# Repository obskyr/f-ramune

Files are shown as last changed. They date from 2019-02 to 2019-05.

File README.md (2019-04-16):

# F-Ramune

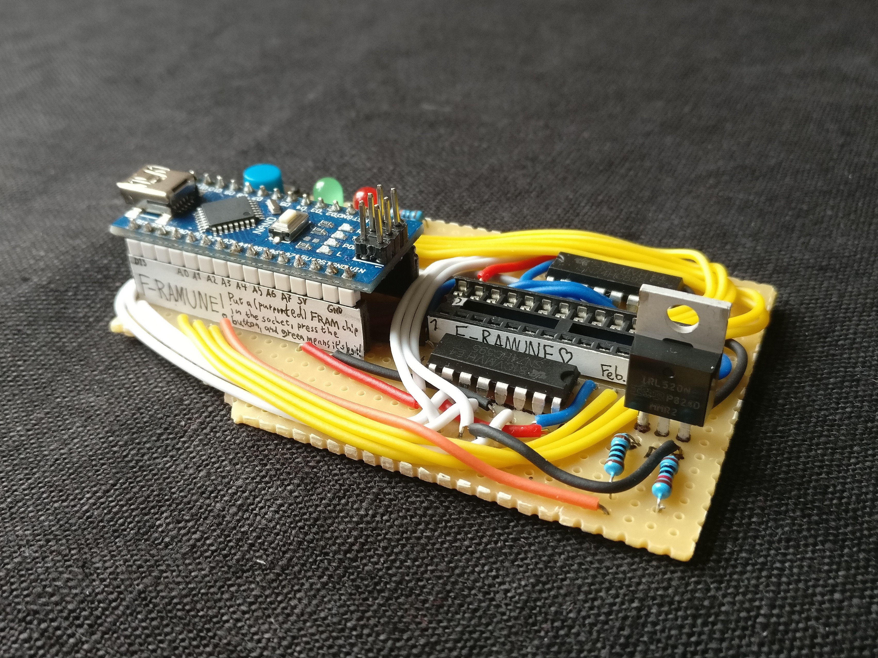
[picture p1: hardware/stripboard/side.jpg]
F-Ramune


F-Ramune is a device that lets you test and program 28-pin FRAM chips (e.g. the FM1808 family)! It lets you:

* Test that a chip is genuine FRAM!
* Test that all of the memory cells of an FRAM chip work!
* Identify a memory chip (size, non-volatility, etc.)
* Read from an FRAM chip!
* Write to an FRAM chip!

It features a reprogrammable pushbutton that lets you quickly test chips – out of the box, it's set to check that a chip is 32 KiB of genuine FRAM in full working order – and a serial interface with accompanying software that lets you program your memory chips from your PC.

I made this to test FM1808s of dubious (i.e. cheap Chinese) origin so that the Game Boy cartridge immortalization mod (link to come) would become more feasible and accessible. I expect that to be the main use of F-Ramune, but it's written in an extensible fashion – if you want to test or program FRAM (or SRAM!) in a different form factor or pinout, not much needs to be changed.

## Getting started

Since F-Ramune is a physical device, you'll first need to build that device. Instructions for this can be found in the [hardware directory](hardware) of the repo. At the moment, there's no PCB version, so it's fairly involved – you have to manually route it on stripboard or breadboard – but it's more than doable.

Once you've built the device, you need to upload the firmware to it. For user-friendliness, F-Ramune's firmware is Arduino-based! Open `software.ino` (in the [`software` directory](software)) in the [Arduino IDE](https://www.arduino.cc/en/main/software), set the board to "Arduino Nano", and click the "upload" button. Bam! Your F-Ramune is now ready to go!

## How to test a chip

Put the chip you want to test in the socket. Press the button to test the chip. Out of the box, upon pressing the button, the LEDs will possibly flash back and forth a bit while testing, and finally indicate:

* **Red** if the chip is 32 KiB of genuine FRAM.
* **Red and green** if the chip is genuine, but faulty memory cells were found.
* **Green** if the chip is 32 KiB of genuine FRAM.

The function of the button can be reprogrammed in [`software.ino`](software/software.ino), if you'd like to check for other traits.

## How to program or analyze a chip

Plug the F-Ramune Arduino into your PC, and put the chip you want to test in the socket. Using the command-line program `framune.py` (found in the `software` directory; requires [Python 3](https://www.python.org/downloads/)) , you can read from, write to, and analyze the properties of the chip. Run `framune.py --help` for details.

## Cool!

F-Ramune is just one part of a larger project, and it's fairly niche, so my instructions here are more terse than they usually are. But fear not! If you have any questions, there are any issues, or you just want to talk, you can contact me in the following ways:

* [@obskyr](https://twitter.com/obskyr) on Twitter, or
* [E-mail](mailto:powpowd@gmail.com) me!

For a quick response, writing to me on Twitter is your best bet. If you built F-Ramune, especially, I would *love* to hear about it!

Enjoy! ☆

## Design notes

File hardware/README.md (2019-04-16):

# The F-Ramune hardware

As of yet, there's no PCB version of F-Ramune, but here are some instructions for building it on stripboard or breadboard!

The bill of materials is as following:

| Part | Description | Number required |
| --- | --- | --- |
| Arduino Nano | | 1 |
| ZIF Socket with DIP-28 footprint | To fit SMD parts a [SOIC-28 ZIF socket](https://www.adafruit.com/product/1281). To also be compatible with DIP chips, a DIP-28 ZIF socket can be used as the bottom layer in a… socket cake. | 1
| 74HC595 | 8-bit SIPO shift register | 2 |
| IRL520N | N-channel MOSFET | 1 |
| Green LED | | 1 |
| Red LED | | 1 |
| Pushbutton | | 1 |
| 10 kΩ resistor | | 1 |
| 100 Ω resistor | | 1 |
| 330 Ω resistor | | 2 |

## Tips for all versions

The schematic specifies the transistor to be an IRL520N, but **any N-channel MOSFET with an I<sub>D</sub>** (drain current) **of 200 mA or higher, a V<sub>GS</sub>** (gate threshold) **of 4.5 V or lower and an R<sub>DS(ON)</sub>** (on-resistance) **of 1 Ω or lower works**. The V<sub>GS</sub> requirement is for ~5 V logic signals to work. The R<sub>DS(ON)</sub> of 1 Ω is calculated based on an assumed max supply current for the memory chip of 200 mA and a max allowable voltage drop of 0.2 V (0.2 A / 0.2 V = 1 Ω). Using a more realistic max supply current of 140 mA and/or a more forgiving voltage drop limit, you can arrive at a higher max R<sub>DS(ON)</sub>, and it'll probably still work fine – albeit with less leeway. If you've got MOSFETs lying around, check out their datasheets and see if they're reasonably close to the requirements!

<!-- For the eventual PCB version:
## PCB

### Tips for the PCB version

* The schematic specifies an 18.432 MHz crystal, but if you've got a 16 MHz crystal lying around, you can use that – it'll just make the serial communication less reliable (0% timing error for 18.432 MHz vs. ~3.5% error for 16). This might still work fine, but it's possible it'll cause trouble with some serial adapters. 
-->

## Stripboard

There's no layout diagram for building F-Ramune on stripboard (since apparently there's no good digital stripboard design program!?), but it's a very reliable and permanent way to build it, so why not give it a shot? Using [the schematic](breadboard-schematic.png), you can put together something most respectable. Here's my finished stripboard:

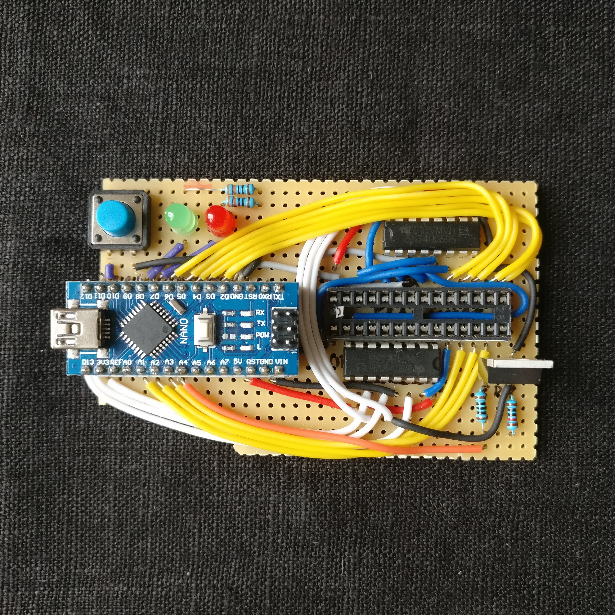
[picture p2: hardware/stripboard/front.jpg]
Stripboard front
  
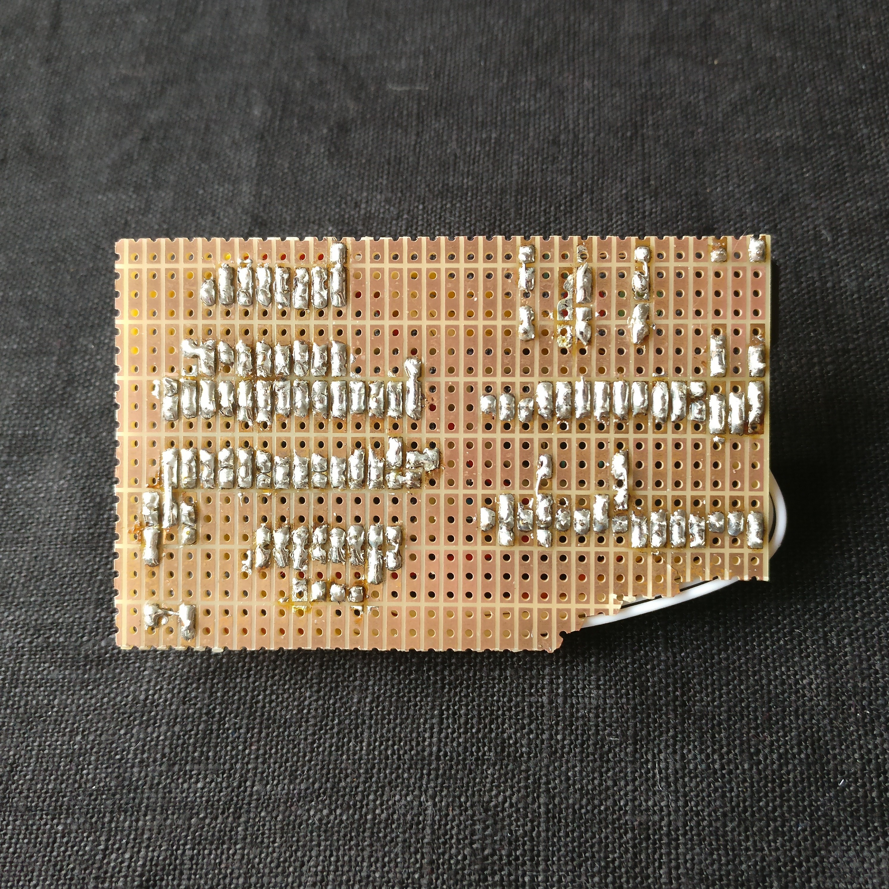
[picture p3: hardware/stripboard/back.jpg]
Stripboard back
  

Don't make the mistake I did and leave too little space for the socket – preferably, solder in whatever socket you're using *before* any wires. Measure twice, cut once, y'know?

## Breadboard

I wouldn't recommend breadboarding F-Ramune – breadboards are unreliable, and the device uses high-speed signals and has to be quite picky with voltages. If you would like to try, though, the breadboard schematic and layout can be found in `breadboard.fzz`, which is a [Fritzing](http://fritzing.org/) file. Either install Fritzing and open that file, or take a gander at the image versions of [the schematic](breadboard-schematic.png) and [the layout diagram](breadboard.png). The layout is somewhat optimistically routed, so some spur-of-the-moment re-routings may need to be done as space gets tight. Here's the finished product:

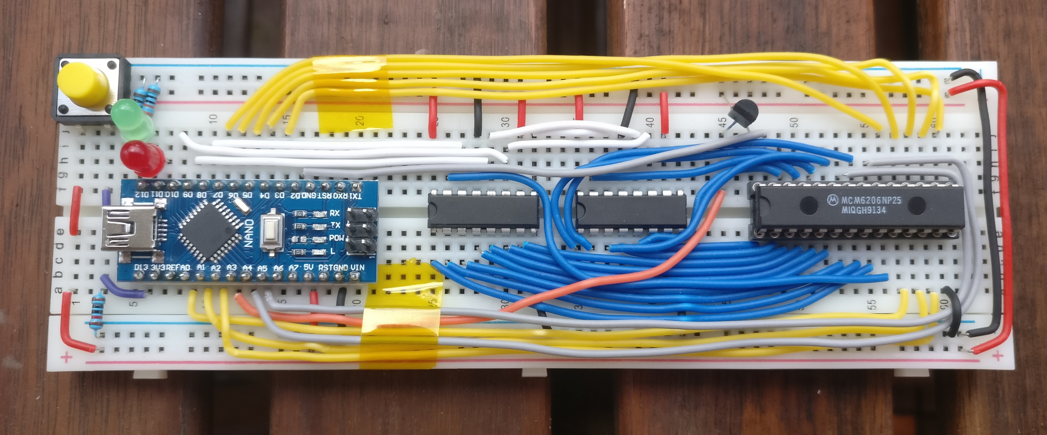
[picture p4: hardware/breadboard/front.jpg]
Routed breadboard


### Tips for breadboarding F-Ramune

* Use a high-quality breadboard! Although FRAM chips consume next to no current, SRAM chips can consume up to 140 mA. Channeling that much via a breadboard with poor connections and bizarrely resistive power rails is a fool's errand – I learned this the hard way.
* If you're using a breadboard of lesser quality, keep the following in mind:
    * When you insert a wire or a pin, make sure it feels like it's being gripped (and before you insert an IC, check those holes with a wire first). If it doesn't, that hole may be intermittent or flat-out broken. You can remedy this by using a different hole on the same row, replacing the strip on that particular row, or [jamming a resistor leg into it](https://twitter.com/obskyr/status/1096047043683012609).
    * You may need to run wires directly to the memory chip's V+ and ground pins from the holes right by the Arduino, since going via the power rails might prove too high-resistance. Adding more bridge wires (like the ones on the far right in the breadboard diagram) may also help, albeit not as much.
* The pins on a TO-220 package such as the MOSFET here are highly destructive to breadboard holes. Use a gripping implement to turn the thin part of the pins 45–90° before inserting it, so the pins don't get gripped lengthwise and bend the breadboard's connectors out of shape.

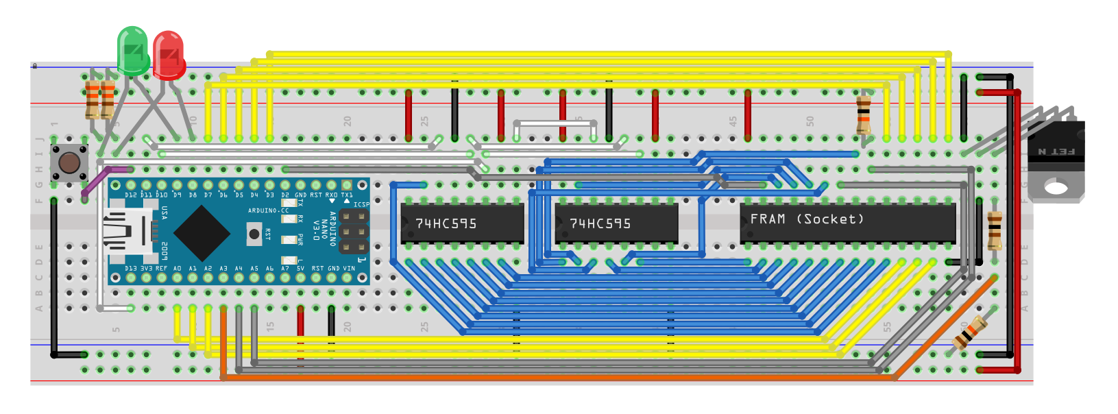
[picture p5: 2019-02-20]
hardware/breadboard/breadboard.png

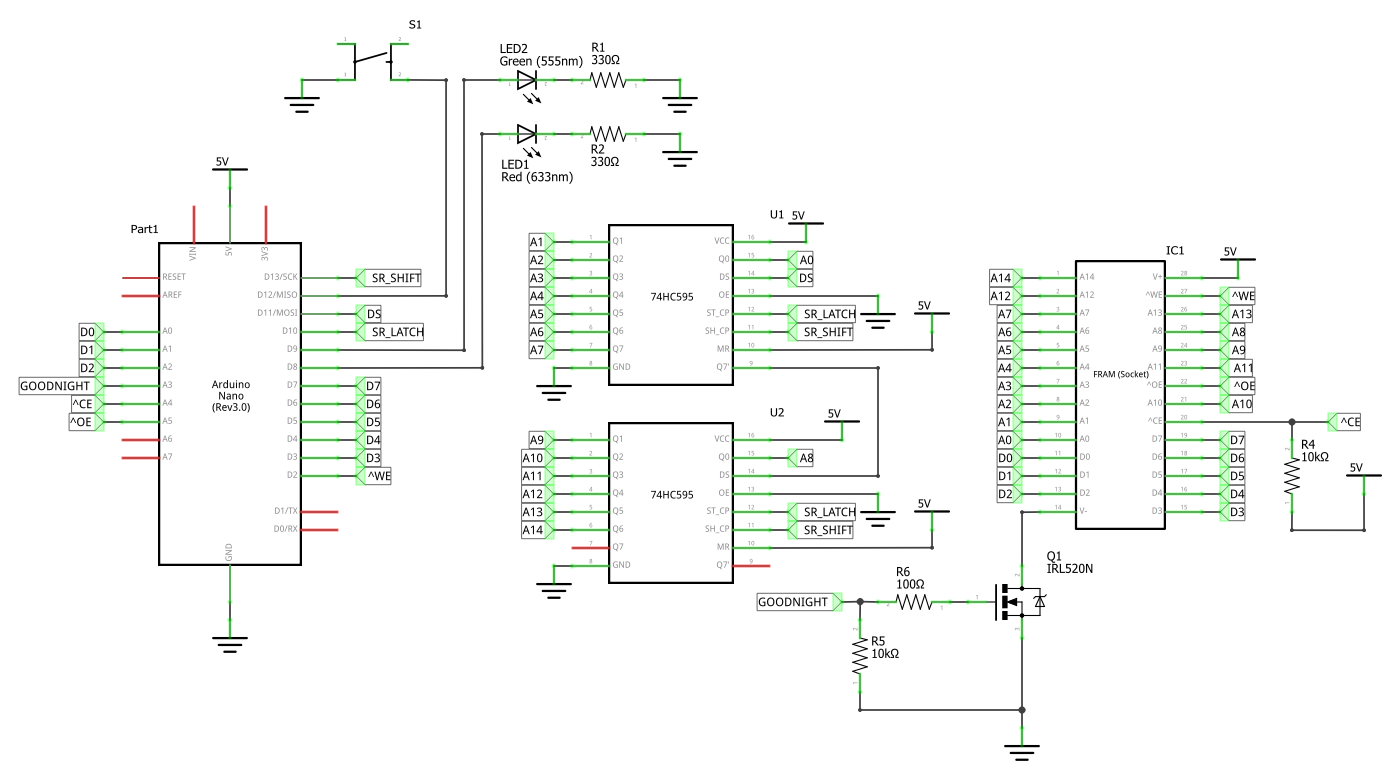
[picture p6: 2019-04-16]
hardware/breadboard/breadboard_schematic.png

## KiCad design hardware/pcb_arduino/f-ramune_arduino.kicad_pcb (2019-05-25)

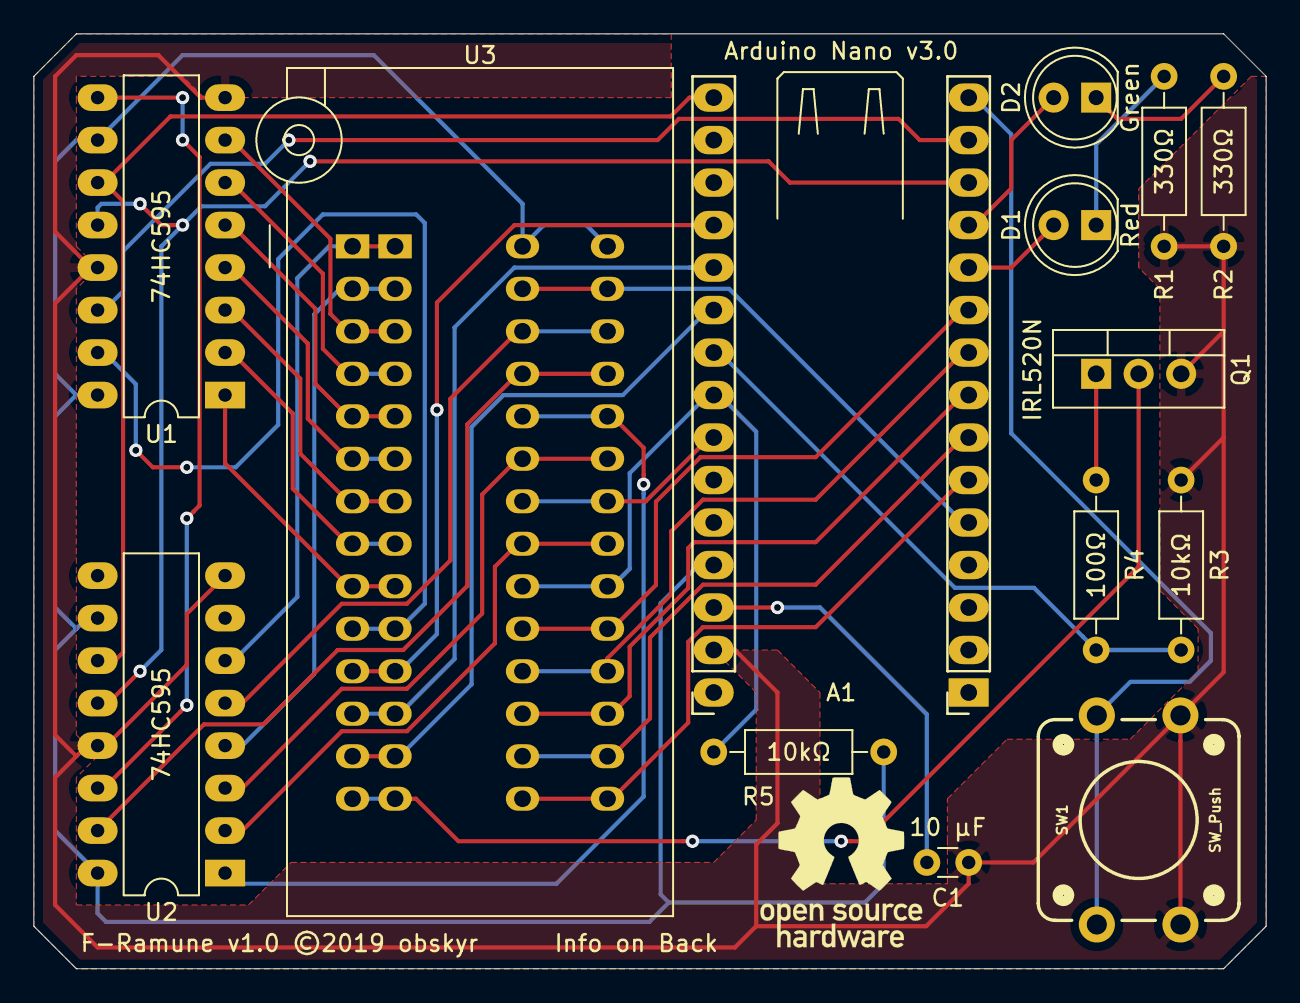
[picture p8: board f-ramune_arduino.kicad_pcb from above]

Board: 2 copper layers, 73.7 x 55.9 mm, 14 parts (0 on the bottom side), 41 nets.

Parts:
A1: Arduino Nano v3.0; Socket_Strip_Arduino_Nano
C1: 10 µF; C_Disc_D3.0mm_W1.6mm_P2.50mm
D1: Red; LED_D5.0mm
D2: Green; LED_D5.0mm
Q1: IRL520N; TO-220-3_Vertical
R1, R2: 330Ω; R_Axial_DIN0207_L6.3mm_D2.5mm_P10.16mm_Horizontal
R3, R5: 10kΩ; R_Axial_DIN0207_L6.3mm_D2.5mm_P10.16mm_Horizontal
R4: 100Ω; R_Axial_DIN0207_L6.3mm_D2.5mm_P10.16mm_Horizontal
SW1: SW_Push; TACTILE_SWITCH_PTH_12MM
U1, U2: 74HC595; DIP-16_W7.62mm_LongPads
U3: Memory (Socket); ZIF_Socket_DIP-28_With_Alternatives

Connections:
+5V: A1.27, R5.1, U1.10, U1.16, U2.10, U2.16, U3.28
A0: U1.15, U3.10
A1: U1.1, U3.9
A2: U1.2, U3.8
A3: U1.3, U3.7
A4: U1.4, U3.6
A5: U1.5, U3.5
A6: U1.6, U3.4
A7: U1.7, U3.3
A8: U2.15, U3.25
A9: U2.1, U3.24
A10: U2.2, U3.21
A11: U2.3, U3.23
A12: U2.4, U3.2
A13: U2.5, U3.26
A14: U2.6, U3.1
D0: A1.19, U3.11
D1: A1.20, U3.12
D2: A1.21, U3.13
D3: A1.6, U3.15
D4: A1.7, U3.16
D5: A1.8, U3.17
D6: A1.9, U3.18
D7: A1.10, U3.19
GND: A1.29, C1.1, Q1.3, R1.2, R2.2, R3.1, SW1.1, U1.8, U1.13, U2.8, U2.13
Goodnight: A1.22, R3.2, R4.2
unnamed: A1.11, D1.2
unnamed: A1.12, D2.2
unnamed: A1.15, SW1.2
unnamed: A1.28, C1.2
unnamed: D1.1, R1.1
unnamed: D2.1, R2.1
unnamed: Q1.1, R4.1
unnamed: Q1.2, U3.14
unnamed: U1.9, U2.14
SR_Data: A1.14, U1.14
SR_Latch: A1.13, U1.12, U2.12
SR_Shift: A1.16, U1.11, U2.11
~CE: A1.23, R5.2, U3.20
~OE: A1.24, U3.22
~WE: A1.5, U3.27

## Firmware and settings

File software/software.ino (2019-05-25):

#include <Bounce2.h>
#include "channelio.hpp"
#include "memorychip.hpp"
#include "serialinterface.hpp"

// If you want to use an MCU or pinout other than the ones found in the
// hardware directory, change these settings here to your liking. 
#if !defined(PCB_LAYOUT) && (defined(BREADBOARD_LAYOUT) || defined(ARDUINO_AVR_NANO))

// Memory chip control pins
#define PIN_MEMORY_POWER A3
#define PIN_MEMORY_POWER_ON_STATE HIGH
#define PIN_MEMORY_CE    A4
#define PIN_MEMORY_OE    A5
#define PIN_MEMORY_WE    2

// Memory chip address channel
// Latch pin: 10 (SS - doesn't need to be SS, but might as well be)
// When SPI is active, don't forget: MISO's direction is overridden
// to be an input (but the pull-up is still available), and SS has to
// stay configured as an output to stay master!
// Within those config constraints, though, they can be used for unrelated IO.
Output_SpiShiftRegister<uint16_t> ADDRESS_CHANNEL(20000000, SPI_MODE0, 10);

// Memory chip data channel
// Note that INPUT_PULLUP here is important - otherwise, reading when there's
// no chip connected will read back what was just written (ghooost values).
// 5 bits starting at bit #3, via port D
InputOutput_Port DATA_CHANNEL_PORT_1(INPUT_PULLUP, &PIND, &PORTD, &DDRD, 3, 3, 5);
// 3 bits starting at bit #0, via port C
InputOutput_Port DATA_CHANNEL_PORT_2(INPUT_PULLUP, &PINC, &PORTC, &DDRC, 0, 0, 3);
InputOutput_Port* DATA_CHANNEL_PORTS[] = {
    &DATA_CHANNEL_PORT_1,
    &DATA_CHANNEL_PORT_2
};
InputOutputChannelSet<uint8_t, InputOutput_Port> DATA_CHANNEL(
    sizeof(DATA_CHANNEL_PORTS) / sizeof(*DATA_CHANNEL_PORTS),
    DATA_CHANNEL_PORTS
);

// Buttons 'n' lights
#define PIN_TEST_BUTTON 12
#define PIN_HAPPY_LED    9
#define PIN_FROWNY_LED   8

#else

// I decree that the IO settings for the circuit board version shall go here.

#endif

MemoryChip MEMORY_CHIP(&ADDRESS_CHANNEL, &DATA_CHANNEL,
                       PIN_MEMORY_CE, PIN_MEMORY_OE, PIN_MEMORY_WE,
                       PIN_MEMORY_POWER, PIN_MEMORY_POWER_ON_STATE);
SerialInterface SERIAL_INTERFACE(&Serial, &MEMORY_CHIP);

Bounce TEST_BUTTON = Bounce();

void testChip()
{
    MemoryChipKnownProperties prevKnownProperties;
    MemoryChipProperties prevProperties;
    MEMORY_CHIP.getProperties(&prevKnownProperties, &prevProperties);
    MEMORY_CHIP.analyze();
    MemoryChipKnownProperties knownProperties;
    MemoryChipProperties properties;
    MEMORY_CHIP.getProperties(&knownProperties, &properties);

    if (!(knownProperties.isOperational && properties.isOperational)) {
        // No chip connected: li'l "wat?" animation.
        int i = 0;
        int timesToBlink = 3;
        while (i < timesToBlink) {
            digitalWrite(PIN_HAPPY_LED, HIGH);
            digitalWrite(PIN_FROWNY_LED, HIGH);
            delay(333);
            digitalWrite(PIN_HAPPY_LED, LOW);
            digitalWrite(PIN_FROWNY_LED, LOW);
            i++;
            if (i < timesToBlink) {delay(333);}
        }
    } else if (!(
        // To change the properties the test button tests, change these here criteria!
        // These criteria test that the chip is fast 32 KiB non-volatile memory.
        // That is, FRAM. (Or something equivalent, but it's gonna be FRAM.)
        (knownProperties.size && properties.size == 0x8000) &&
        (knownProperties.isNonVolatile && properties.isNonVolatile) &&
        (knownProperties.isSlow && !properties.isSlow)
    )) {
        // Incorrect properties: red light.
        digitalWrite(PIN_FROWNY_LED, HIGH);
    } else {
        // And for posterity, we test that all memory cells work, too.
        // Since testing *all* addresses takes some time, this requires
        // a little "working..." animation.
        uint8_t blinkState = HIGH;
        digitalWrite(PIN_HAPPY_LED, HIGH);
        unsigned long int prevBlinkMillis = millis();
        bool allAddressesWork = true;
        for (uint32_t windowStart = 0; windowStart < properties.size; windowStart += 512) {
            uint32_t windowEnd = windowStart + 512;
            windowEnd = windowEnd <= properties.size ? windowEnd : properties.size;
            if (!MEMORY_CHIP.addressesWorkBetween(windowStart, windowEnd)) {
                allAddressesWork = false;
                break;
            }

            unsigned long int curMillis = millis();
            if (curMillis - prevBlinkMillis >= 333) {
                blinkState = !blinkState;
                digitalWrite(PIN_HAPPY_LED, blinkState);
                digitalWrite(PIN_FROWNY_LED, !blinkState);
                prevBlinkMillis = curMillis;
            }
        }

        digitalWrite(PIN_HAPPY_LED, LOW);
        digitalWrite(PIN_FROWNY_LED, LOW);
        delay(333);
        if (allAddressesWork) {
            // Correct properties and all cells working: green light.
            digitalWrite(PIN_HAPPY_LED, HIGH);
        } else {
            // Correct properties but broken memory cells: green and red light.
            digitalWrite(PIN_HAPPY_LED, HIGH);
            digitalWrite(PIN_FROWNY_LED, HIGH);
        }

        // If you don't want to test the entire address space,
        // comment out the rest of this block and uncomment this line:
        // digitalWrite(PIN_HAPPY_LED, HIGH);
    }

    MEMORY_CHIP.setProperties(&prevKnownProperties, &prevProperties);
}

void setup()
{
    Serial.begin(115200);
    MEMORY_CHIP.initPins();
    TEST_BUTTON.attach(PIN_TEST_BUTTON, INPUT_PULLUP);
    TEST_BUTTON.interval(25);
    pinMode(PIN_HAPPY_LED, OUTPUT);
    pinMode(PIN_FROWNY_LED, OUTPUT);
}

void loop()
{
    TEST_BUTTON.update();
    if (!SERIAL_INTERFACE.update()) {
        if (TEST_BUTTON.fell()) {
            digitalWrite(PIN_HAPPY_LED, LOW);
            digitalWrite(PIN_FROWNY_LED, LOW);
        } else if (TEST_BUTTON.rose()) {
            MEMORY_CHIP.powerOn();
            testChip();
            MEMORY_CHIP.powerOff();
        }
    }
}

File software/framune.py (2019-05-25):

#!/usr/bin/env python3

import argparse
import json
import os
import struct
import sys
import serial
from binascii import crc32
from collections import OrderedDict
from contextlib import contextmanager

BAUD_RATE = 115200
MIN_TIMEOUT = 1

PROTOCOL_VERSION = 0
ENDIANNESS = '>'

def serial_without_dtr(port, *args, **kwargs):
    """Construct a Serial object with DTR immediately disabled.
    On systems where pySerial supports this, this will prevent an Arduino from
    resetting when a serial connection is opened. On other systems, a hardware
    workaround (e.g. a 10 µF capacitor between RST and ground) is needed.
    """
    ser = serial.Serial(None, *args, **kwargs)
    ser.port = port
    ser.dtr = 0
    if port is not None: # To match what pySerial does.
        ser.open()
    return ser

def appropriate_timeout(length):
    """Return a reasonable timeout value for transferring `length`
    bytes at F-Ramune's baud rate."""
    return max(MIN_TIMEOUT, 1.5 * (length / (BAUD_RATE // 8)))

@contextmanager
def temp_timeout(ser, timeout):
    original_timeout = ser.timeout
    ser.timeout = timeout
    yield
    ser.timeout = original_timeout

class Framune(object):
    def __init__(self, serial_port):
        if hasattr(serial_port, 'port'):
            self.serial_port = serial_port.port
            self._serial = serial_port
        else:
            self.serial_port = serial_port
            self._serial = serial_without_dtr(serial_port, BAUD_RATE,
                                              timeout=MIN_TIMEOUT,
                                              inter_byte_timeout=MIN_TIMEOUT)
        self._chip = MemoryChip(None, None, None, None, framune=self)
    
    def __enter__(self):
        return self

    def __exit__(self, *args):
        self.close()

    def close(self):
        self._serial.close()
    
    @property
    def chip(self):
        return self._chip
    
    @chip.setter
    def chip(self, chip):
        self._set_and_analyze_chip(chip)
    
    def _read(self, length=1):
        try:
            data = self._serial.read(length)
            if len(data) < length:
                raise TimeoutError
        except (serial.SerialTimeoutException, TimeoutError):
            raise TimeoutError("F-Ramune did not respond in time.")
        else:
            return data
    
    def _write(self, data):
        self._serial.write(data)

    def _read_uint(self, fmt, length):
        return struct.unpack(fmt, self._read(length))[0]
    
    def _write_uint(self, fmt, n):
        self._write(struct.pack(fmt, n))

    def _read_byte(self):
        return self._read_uint(ENDIANNESS + 'B', 1)
    
    def _write_byte(self, n):
        self._write_uint(ENDIANNESS + 'B', n)
    
    def _read_uint16(self):
        return self._read_uint(ENDIANNESS + 'H', 2)

    def _write_uint16(self, n):
        self._write_uint(ENDIANNESS + 'H', n)

    def _read_uint32(self):
        return self._read_uint(ENDIANNESS + 'I', 4)

    def _write_uint32(self, n):
        self._write_uint(ENDIANNESS + 'I', n)

    def _command(self, command):
        self._write_byte(command)
        if self._read_byte() == command:
            self._write_byte(0x00)
        else:
            self._write_byte(0x01)
            raise ConnectionError("Command didn't reach F-Ramune intact.")
    
    def _set_and_analyze_chip(self, chip):
        self._command(0x01)
        self._write(chip.known_status_to_bytes())
        self._write(chip.to_bytes())
        self._chip = MemoryChip.from_bytes(
            self._read(MEMORY_CHIP_KNOWN_DATA_STRUCTURE_SIZE),
            self._read(MEMORY_CHIP_DATA_STRUCTURE_SIZE),
            framune=self
        )

    def get_version(self):
        """Return the protocol version of the F-Ramune."""
        self._command(0x00)
        return self._read_uint16()
    
    def version_matches(self):
        """Return True if the F-Ramune has the same protocol version
        as the script does; False if not.
        """
        return self.get_version() == PROTOCOL_VERSION
    
    def analyze(self):
        self._set_and_analyze_chip(MemoryChip(None, None, None, None))

    def read(self, address, length):
        """Return up to `length` bytes read starting at `address` from
        the memory chip currently connected to the F-Ramune.
        """
        self._command(0x02)
        self._write_uint32(address)
        self._write_uint32(length)
        length = self._read_uint32()

        with temp_timeout(self._serial, appropriate_timeout(length)):
            data = self._read(length)
        
        received_crc = self._read_uint32()
        computed_crc = crc32(data)
        if received_crc != computed_crc:
            raise ConnectionError("The computed checksum didn't match the one "
                                  "received from the F-Ramune.")
        
        return data
    
    def write(self, address, data):
        """Write the bytes `data` to the memory chip currently connected to
        the F-Ramune, starting at `address`."""
        length = len(data)
        self._command(0x03)
        # Unused at the moment. Who needs EEPROM support anyway...
        is_slow = self._read_byte()
        self._write_uint32(address)
        self._write_uint32(length)
        length = self._read_uint32()
        data = data[:length]

        with temp_timeout(self._serial, appropriate_timeout(length)):
            self._write(data)
            # Receiving the CRC really only transfers 4 bytes, but the F-Ramune
            # operates on all of the bytes written to compute it, so it takes
            # time, and thus needs a more lenient timeout. appropriate_timeout
            # does that job well enough (it's a bit too lenient here, even).
            received_crc = self._read_uint32()
        error_code = self._read_byte()
        computed_crc = crc32(data)
        if received_crc != computed_crc:
            raise ConnectionError("The computed checksum didn't match the one "
                                  "received from the F-Ramune.")
        if error_code != 0:
            raise ConnectionError("Write failed. "
                                  "Is there really a memory chip connected?")
        return length

def framune_updating_property(internal_name):
    def getter(self):
        return getattr(self, internal_name)
    prop = property(getter)
    def setter(self, value):
        setattr(self, internal_name, value)
        if self._framune is not None:
            self._framune.chip = self
    with_setter = prop.setter(setter)
    return with_setter
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

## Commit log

2019-01-30 Draw schematic.
    Along with adding .gitignore.
    [fram-tester.sch]
2019-01-31 Add Fritzing breadboard diagram.
    [fram-tester_breadboard.fzz]
2019-01-31 Overhaul breadboard to use Arduino Nano.
    Turns out the FM18W08 (as opposed to the regular FM1808) is CMOS logic, which means the lower cutoff for a logical 1 is 3.5V. So... for compatibility, a 3.3V logic MCU needs the ability to switch bet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
    [fram-tester_breadboard.fzz]
2019-01-31 Reroute breadboard a wee bit.
    [fram-tester_breadboard.fzz]
2019-01-31 Nevermind! It was better before.
    [fram-tester_breadboard.fzz]
2019-01-31 Moved FRAM control pins to potentially make way for ICSP.
    [fram-tester_breadboard.fzz]
2019-02-01 Add indicator LEDs and test button to breadboard.
    The ICSP pins be darned for the moment - the breadboard and circuit board versions might as well have different pinouts.
    [fram-tester_breadboard.fzz]
2019-02-02 Reroute breadboard to leave pins 0 and 1 unconnected.
    As it turns out, USB serial goes via pins 0 and 1 on the MCU on the Arduino too, so they can't be connected to other things if serial is used. We're really using ALL the pins! Exciting!
    [fram-tester_breadboard.fzz]
2019-02-09 A whole lot of code!
    A system for arbitrarily implemented IO channels (I may have fallen for overgenericization) and a class for interfacing with memory chips!
    Wow, templates really get messy, don't they? I had to do some seriously impressive somersaults to make separation of API and implementation work both to C++'s and Arduino's constraints at the same ti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
    Oh, and all this is entirely untested. I haven't had the parts to test until just the other day - I've been writing code in the dark. So that's next up, I suppose.
2019-02-09 Fix shifting out too many bits.
    That should be "--", not "++"!
    [channelio.cpp]
2019-02-11 Code galore!
    Lots of fixes (the Arduino IDE lets you turn on -Wall!) and huge optimization. Still isn't fast enough, though.
    Oh, and there's still the minor case of this major bug... https://stackoverflow.com/questions/54632425/is-casting-derived-%e2%86%92-base-wrong-whats-the-alternative
    [channelio.cpp, memorychip.cpp, software.ino]
2019-02-11 Fix ChannelSet compatibility.
    Using templates! Wow!
    [channelio.cpp, software.ino]
2019-02-12 Interface with address shift register via SPI.
    This makes the address setup bizarrely fast, apparently! Good stuff!
    [fram-tester_breadboard.fzz]
2019-02-12 Rename project to f-ramune!
    Enough work has gone into this that it shouldn't have a generic name.
    [breadboard.fzz, f-ramune.sch]
2019-02-13 Add testing code, fix bugs, live life.
    [channelio.cpp, memorychip.cpp, software.ino]
2019-02-14 Initialize control pins properly; change test interface.
    So THAT'S why it seemed like data wasn't persisting across resets. When I was trying to read data back, WE was low, which actually performed a write...
    [memorychip.cpp, software.ino]
2019-02-14 Fix memory potentially being inadvertently written to.
    Memory control pins should start high (inactive), and a pull-up on CE makes sure the memory chip isn't enabled when the control pins are unconfigured.
    Oh, and I flipped a transistor which was the wrong way in the schematic. Whoops!
    [breadboard.fzz]
2019-02-18 Use a low-side MOSFET for switching on/off the memory chip.
    Wow, geez, there are a lot of considerations to be made when cutting power to an IC! This commit implements and explains a whole lot of those.
    The main reason for using a MOSFET over a BJT is that BJTs have fairly high voltage drop, which could potentially be troublesome.
    [breadboard.fzz]
2019-02-18 Move breadboard chips to the left one row.
    Just a liiiittle bit more compact.
    [breadboard.fzz]
2019-02-20 Use internal pull-up resistor for button.
    Turns out the MISO pin, even when overridden to be an input by the SPI peripheral, can use the internal pull-up. That makes one less component!
    [breadboard.fzz]
2019-03-01 Add "set memory chip" serial command.
    Along with a few miscellaneous bug fixes and additions.
    [framune.py, memorychip.cpp, software.ino]
2019-03-01 Make chip analysis work *mwah* just like-a mama used to make.
    Along with integrating chip analysis into the "set chip command" and miscellaneous fixes and such.
    [framune.py, memorychip.cpp, software.ino]
2019-03-01 Finally implement that test button!!!
    You know that test button that really was the entire point of the device? The whole idea? After a bunch of bells and whistles (and a... serial interface!?), it finally does what it set out to do!!!
2019-03-06 KiCAD version of Arduino schematic.
    Along with a li'l bit of restructuring.
    [breadboard.fzz, f-ramune.sch, f-ramune_arduino.kicad_pcb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]
2019-03-09 Add write command; fix bugs.
    That's all the commands!
    [framune.py, memorychip.cpp]
2019-03-28 Have memory chip unpowered during downtime.
    This way, you won't have to switch out the chip while it's powered, which might cause serious trouble.
    [memorychip.cpp, software.ino]
2019-04-16 Pictures and instructions!
    That PCB version has to wait. A guy's gotta have priorities, you know?
2019-04-17 Add a PCB version based on the Arduino stripboard F-Ramune. Should be fabricated on blue soldermask for best results.
    [f-ramune_arduino.kicad_pcb, f-ramune_arduino.sch]
2019-04-17 Add more silkscreen indicators onto the board to make it easier to assemble.
    [f-ramune_arduino.kicad_pcb]
2019-04-17 Built gerber files, ready for prototype production! (No BOM though...)
    [f-ramune_arduino-B_Cu.gbl, f-ramune_arduino-B_Mask.gbs, f-ramune_arduino-B_SilkS.gbo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]
2019-04-18 Last-minute silkscreen changes to indicate LED colors and Arduino orientation. Also, delete the redundant NPTH file as this design only has plated holes.
    It's called last-minute, because the cutoff for changes to my PCB order is 2 hours from now and I just noticed the design issue.
    [f-ramune_arduino-B_Cu.gbl, f-ramune_arduino-B_Mask.gbs, f-ramune_arduino-B_SilkS.gbo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]
2019-04-20 Here's a schematic for a bare-AVR version of F-Ramune, including in-circuit programming functionality (do not use with native USB)
    [f-ramune_avr.sch]
2019-05-24 The pin assignments on this switch footprint are wrong. The switch does not close between the long side of the part's pins - it closes around the short side.
    [f-ramune_arduino.kicad_pcb]
2019-05-24 Also, here's an almost-full SMD AVR version of F-Ramune that will probably never be assembled
    [f-ramune_avr.kicad_pcb, f-ramune_avr.sch]
2019-05-25 Extend delay after powering on chip.
    To support... bizarre FRAM chips that just need a bit to get ready once they've been turned on, for some reason? Very very strange.
    I also took the chance to remove a line of test code I'd forgotten to remove before.
2019-05-25 Fix incorrect copyright date on AVR silkscreen.
    [f-ramune_avr.kicad_pcb]
2019-05-25 Add Gerbers for the AVR/SMD version of F-Ramune.
    [f-ramune_avr-B_Cu.gbl, f-ramune_avr-B_Mask.gbs, f-ramune_avr-B_SilkS.gbo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]
2019-05-25 Update / tidy up the Arduino version and add the instructions on the back
    [f-ramune_arduino.kicad_pcb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]

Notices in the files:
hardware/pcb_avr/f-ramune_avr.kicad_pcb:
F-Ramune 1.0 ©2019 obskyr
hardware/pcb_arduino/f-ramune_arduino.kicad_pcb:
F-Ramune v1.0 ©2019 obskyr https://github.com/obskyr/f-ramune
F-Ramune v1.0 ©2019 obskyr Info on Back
